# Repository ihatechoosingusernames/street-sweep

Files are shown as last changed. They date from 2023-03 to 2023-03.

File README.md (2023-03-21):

# street-sweep
A low cost version of the Ferris Sweep ergonomic keyboard.

Based on a [CH552G](https://raw.githubusercontent.com/WeActStudio/WeActStudio.CH552CoreBoard/master/Datasheet/CH552DS1_en.PDF) chip, this PCB can be completely constructed with all components apart from MX switches by JLCPCB for a total of €27.28 (5x PCBs), making for a per-keyboard cost of €10.91.

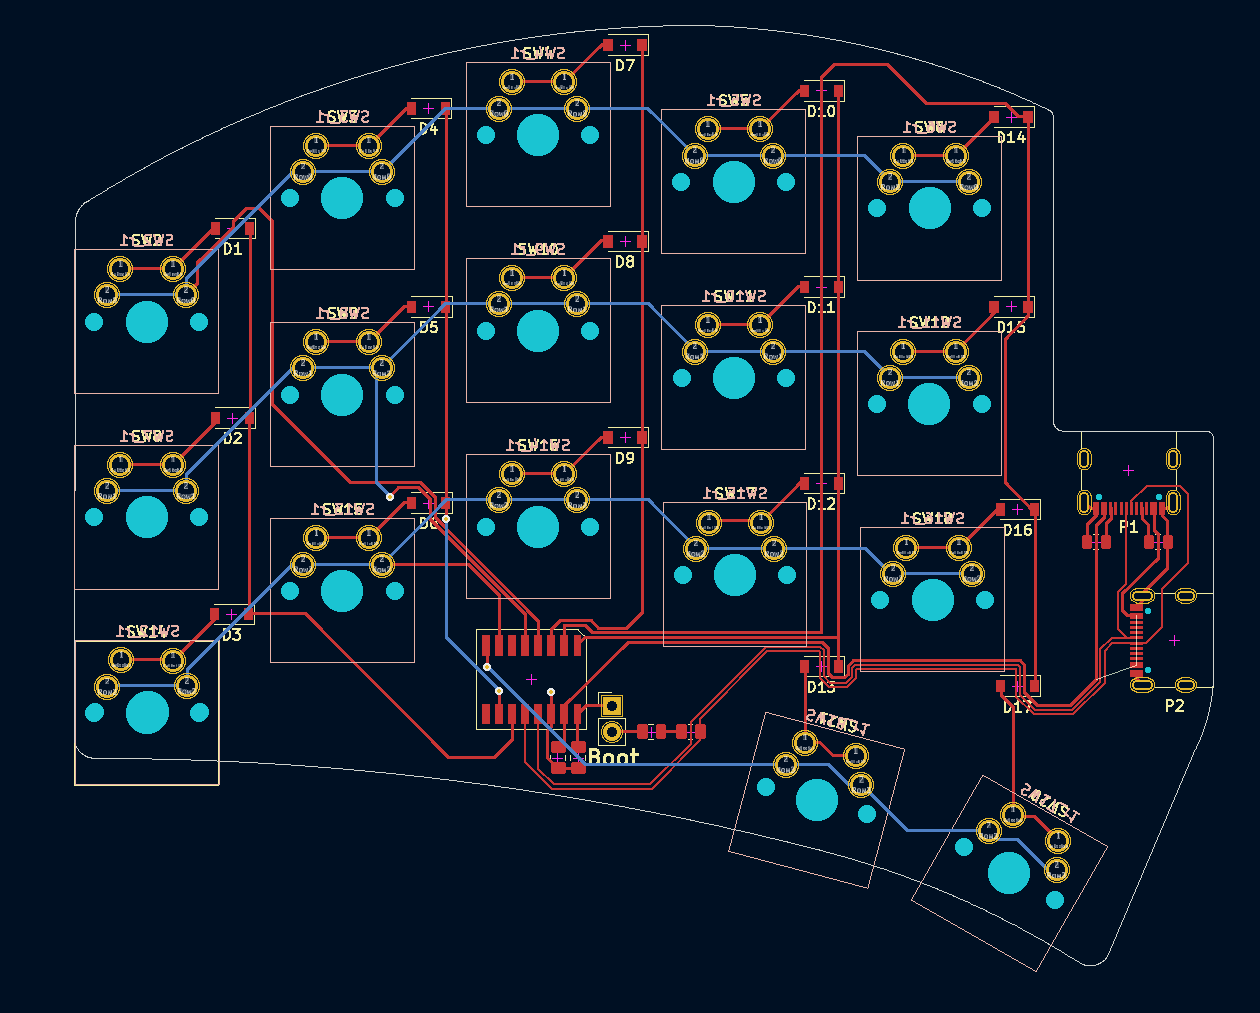
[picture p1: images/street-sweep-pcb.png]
PCB Layout


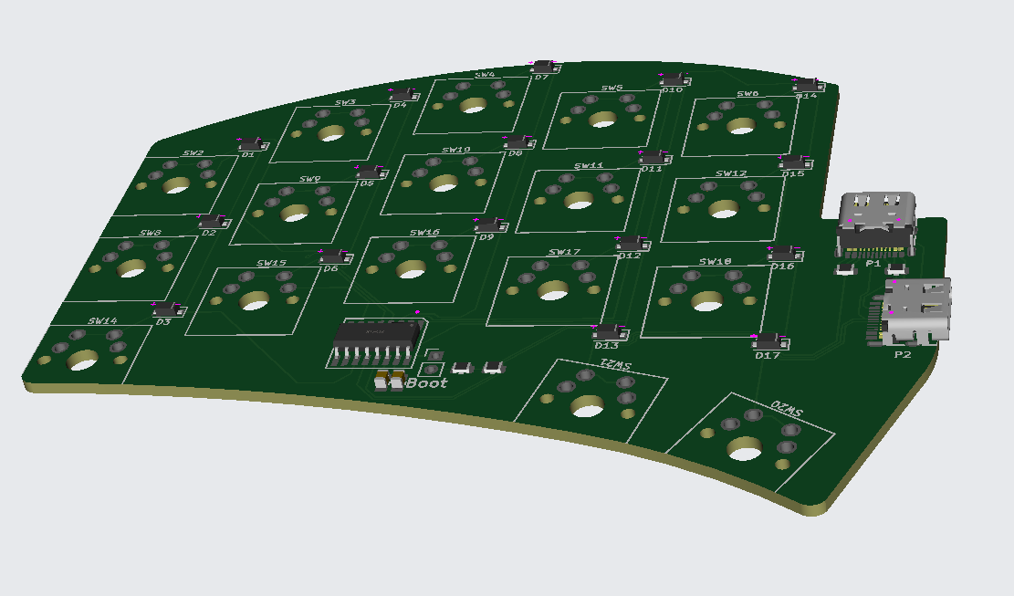
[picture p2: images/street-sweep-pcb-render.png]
PCB 3D Render


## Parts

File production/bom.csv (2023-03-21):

Designator | Footprint | Quantity | Value | LCSC Part #
C1 | 0805 | 1 | 0.1uF
C2 | 0805 | 1 | 0.1uF
D1, D10, D11, D12, D13, D14, D15, D16, D17, D2, D3, D4, D5, D6, D7, D8, D9 | D_SOD-123 | 17 | 1N4148
JP1 | PinHeader_1x02_P2.54mm_Vertical | 1 | Boot
P1, P2 | USB_C_Receptacle_G-Switch_GT-USB-7010ASV | 2 | GT-USB-7010ASV
R1 | 0805 | 1 | 5.1k
R2 | 0805 | 1 | 5.1k
R3 | 0805 | 1 | 5.1k
R4 | 0805 | 1 | 5.1k
SW10, SW10_r1, SW11, SW11_r1, SW12, SW12_r1, SW13_r1, SW14, SW14_r1, SW15, SW15_r1, SW16, SW16_r1, SW17, SW17_r1, SW18, SW18_r1, SW2, SW20, SW21, SW2_r1, SW3, SW3_r1, SW4, SW4_r1, SW5, SW5_r1, SW6, SW6_r1, SW7_r1, SW8, SW8_r1, SW9, SW9_r1 | SW_Cherry_MX_1.00u_PCB | 34 | SW_Push
U1 | CH552G | 1 | CH552G

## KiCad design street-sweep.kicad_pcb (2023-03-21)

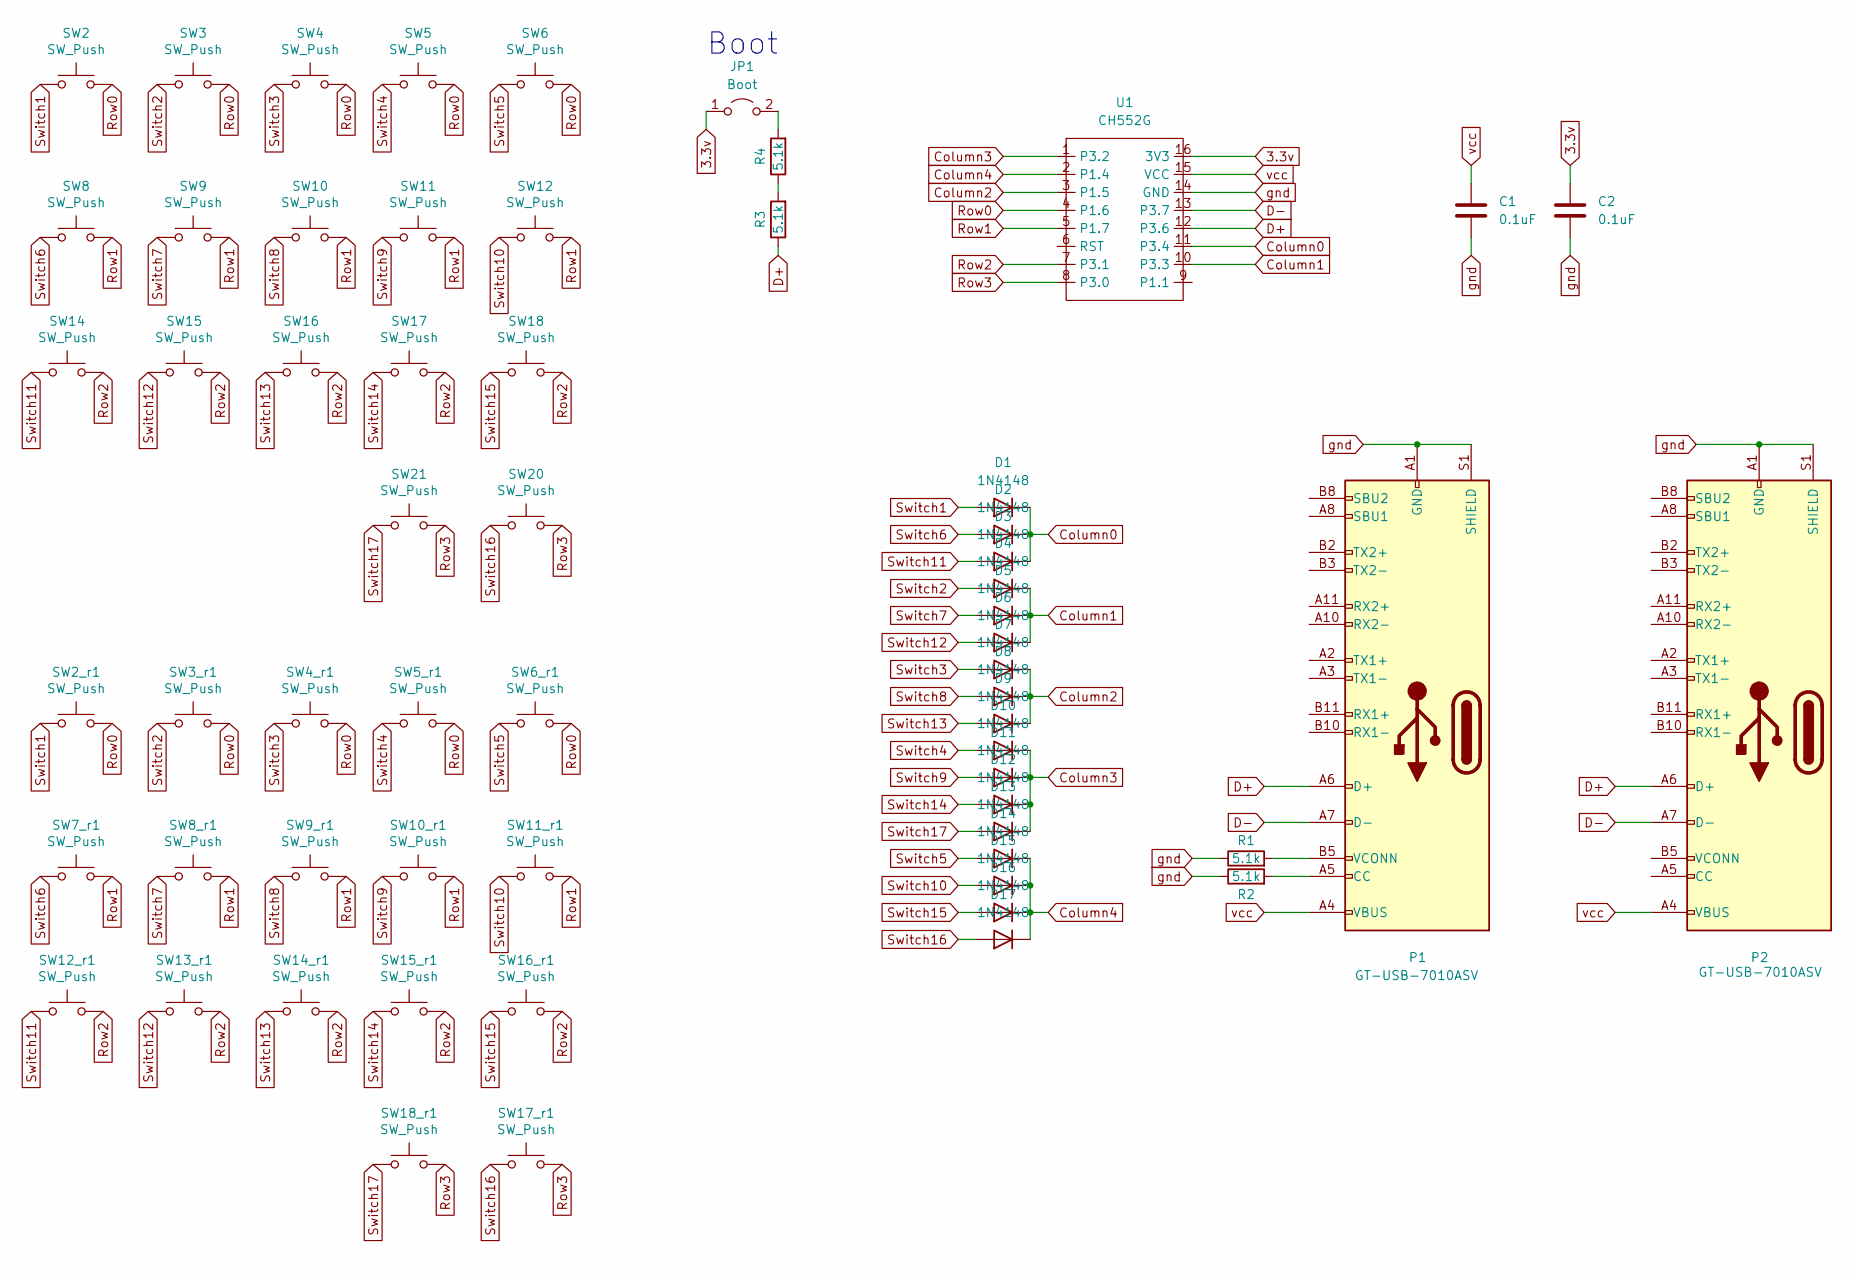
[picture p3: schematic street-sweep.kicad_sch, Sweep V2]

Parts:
C1, C2: 0.1uF; C_0805_2012Metric_Pad1.18x1.45mm_HandSolder
D1, D2, D3, D4, D5, D6, D7, D8, D9, D10, D11, D12, D13, D14, D15, D16, D17: 1N4148; D_SOD-123
JP1: Boot; PinHeader_1x02_P2.54mm_Vertical
P1, P2: GT-USB-7010ASV; USB_C_Receptacle_G-Switch_GT-USB-7010ASV
R1, R2, R3, R4: 5.1k; R_0805_2012Metric
SW2, SW2_r1, SW3, SW3_r1, SW4, SW4_r1, SW5, SW5_r1, SW6, SW6_r1, SW7_r1, SW8, SW8_r1, SW9, SW9_r1, SW10, SW10_r1, SW11, SW11_r1, SW12, SW12_r1, SW13_r1, SW14, SW14_r1, SW15, SW15_r1, SW16, SW16_r1, SW17, SW17_r1, SW18, SW18_r1, SW20, SW21: SW_Push; SW_Cherry_MX_1.00u_PCB
U1: CH552G

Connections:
3.3v: C2.1, JP1.1 (A), U1.16 (3V3)
Column0: D1.1 (K), D2.1 (K), D3.1 (K), U1.11 (P3.4)
Column1: D4.1 (K), D5.1 (K), D6.1 (K), U1.10 (P3.3)
Column2: D7.1 (K), D8.1 (K), D9.1 (K), U1.3 (P1.5)
Column3: D10.1 (K), D11.1 (K), D12.1 (K), D13.1 (K), U1.1 (P3.2)
Column4: D14.1 (K), D15.1 (K), D16.1 (K), D17.1 (K), U1.2 (P1.4)
D+: P1.A6 (D+), P2.A6 (D+), R3.1, U1.12 (P3.6)
D-: P1.A7 (D-), P2.A7 (D-), U1.13 (P3.7)
unnamed: JP1.2 (B), R4.2
unnamed: P1.A5 (CC), R2.2
unnamed: P1.B5 (VCONN), R1.2
unnamed: R3.2, R4.1
Row0: SW2.2, SW2_r1.2, SW3.2, SW3_r1.2, SW4.2, SW4_r1.2, SW5.2, SW5_r1.2, SW6.2, SW6_r1.2, U1.4 (P1.6)
Row1: SW7_r1.2, SW8.2, SW8_r1.2, SW9.2, SW9_r1.2, SW10.2, SW10_r1.2, SW11.2, SW11_r1.2, SW12.2, U1.5 (P1.7)
Row2: SW12_r1.2, SW13_r1.2, SW14.2, SW14_r1.2, SW15.2, SW15_r1.2, SW16.2, SW16_r1.2, SW17.2, SW18.2, U1.7 (P3.1)
Row3: SW17_r1.2, SW18_r1.2, SW20.2, SW21.2, U1.8 (P3.0)
Switch1: D1.2 (A), SW2.1, SW2_r1.1
Switch2: D4.2 (A), SW3.1, SW3_r1.1
Switch3: D7.2 (A), SW4.1, SW4_r1.1
Switch4: D10.2 (A), SW5.1, SW5_r1.1
Switch5: D14.2 (A), SW6.1, SW6_r1.1
Switch6: D2.2 (A), SW7_r1.1, SW8.1
Switch7: D5.2 (A), SW8_r1.1, SW9.1
Switch8: D8.2 (A), SW9_r1.1, SW10.1
Switch9: D11.2 (A), SW10_r1.1, SW11.1
Switch10: D15.2 (A), SW11_r1.1, SW12.1
Switch11: D3.2 (A), SW12_r1.1, SW14.1
Switch12: D6.2 (A), SW13_r1.1, SW15.1
Switch13: D9.2 (A), SW14_r1.1, SW16.1
Switch14: D12.2 (A), SW15_r1.1, SW17.1
Switch15: D16.2 (A), SW16_r1.1, SW18.1
Switch16: D17.2 (A), SW17_r1.1, SW20.1
Switch17: D13.2 (A), SW18_r1.1, SW21.1
gnd: C1.2, C2.2, P1.A1 (GND), P1.A12 (GND), P1.B1 (GND), P1.B12 (GND), P1.S1 (SHIELD), P2.A1 (GND), P2.A12 (GND), P2.B1 (GND), P2.B12 (GND), P2.S1 (SHIELD), R1.1, R2.1, U1.14 (GND)
vcc: C1.1, P1.A4 (VBUS), P1.A9 (VBUS), P1.B4 (VBUS), P1.B9 (VBUS), P2.A4 (VBUS), P2.A9 (VBUS), P2.B4 (VBUS), P2.B9 (VBUS), U1.15 (VCC)

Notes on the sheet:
Boot

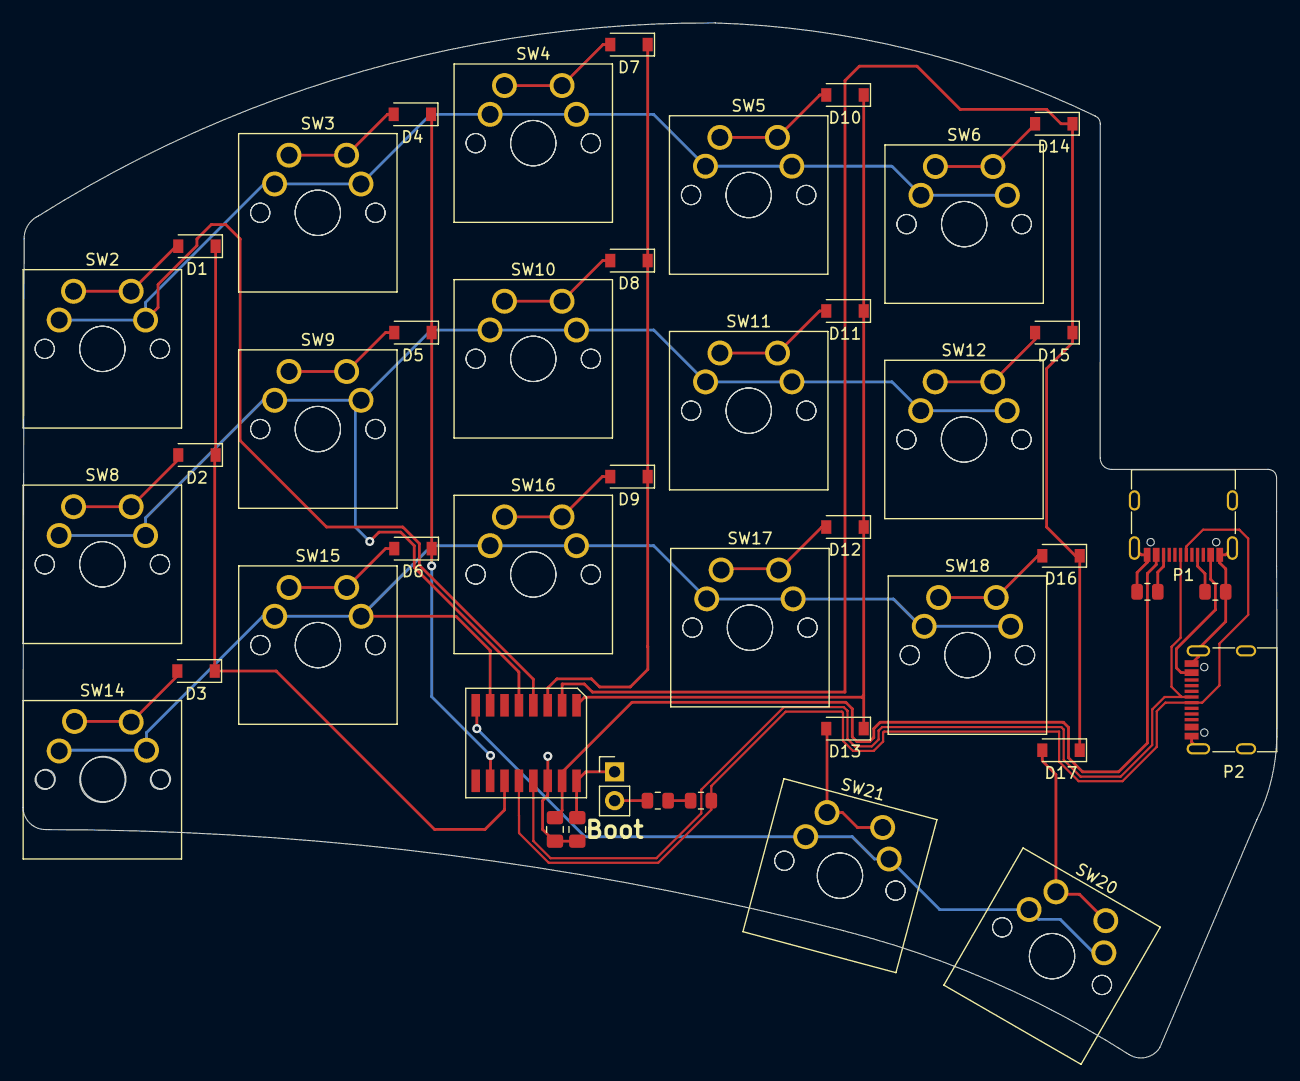
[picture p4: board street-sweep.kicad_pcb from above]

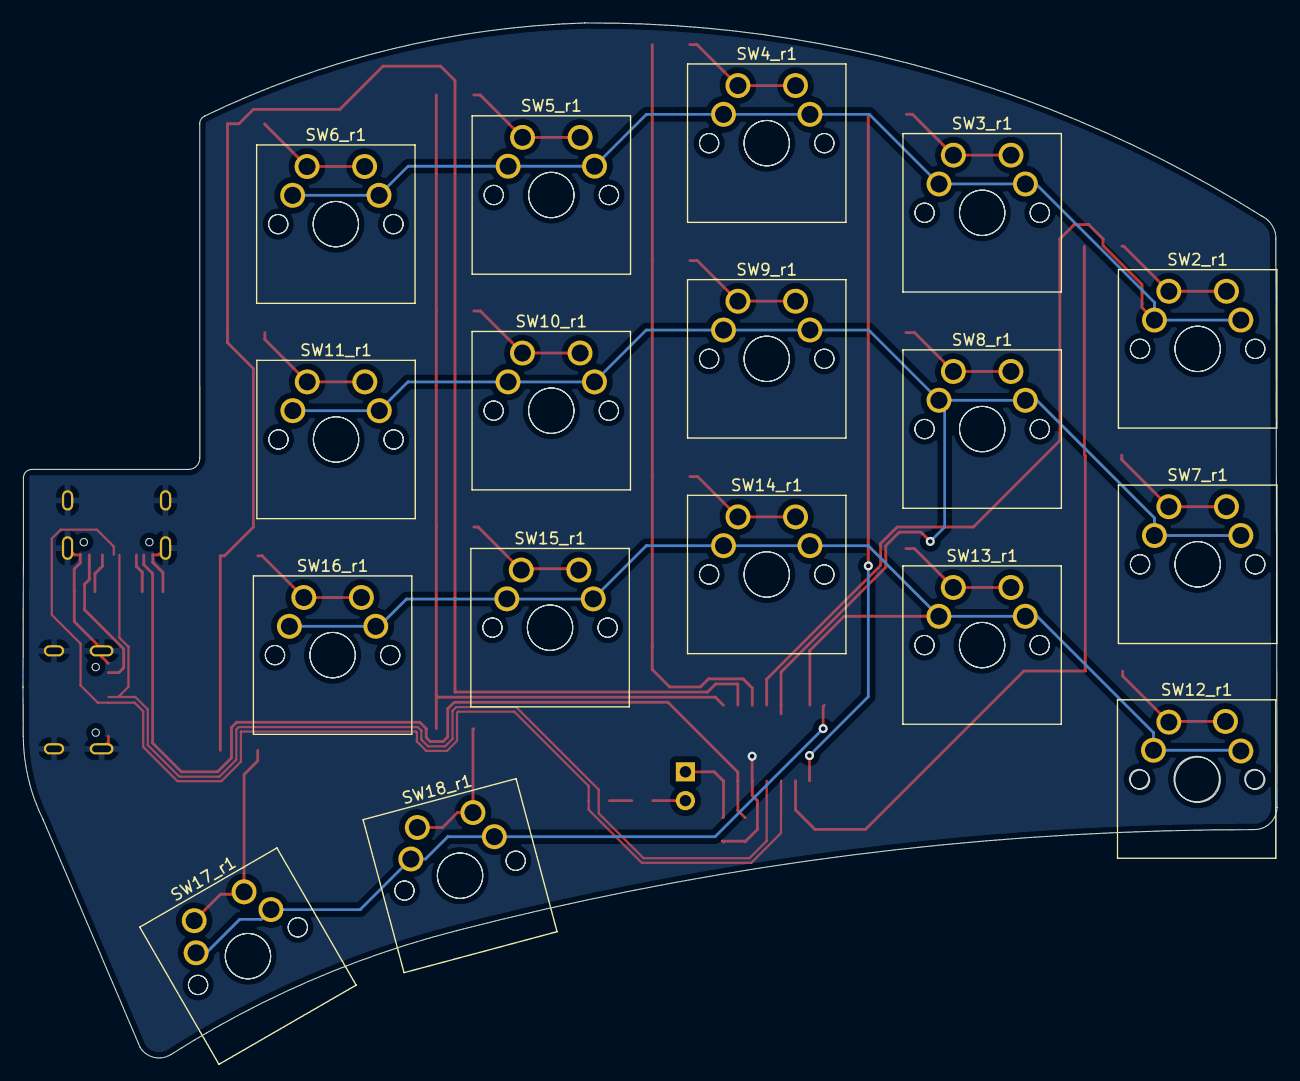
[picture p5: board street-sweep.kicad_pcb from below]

Board: 2 copper layers, 110.6 x 91.3 mm, 61 parts (17 on the bottom side), 35 nets.

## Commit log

2023-03-21 Laid out CH552 Board version with two USB-C ports and fixes for flashing.
    [bom.csv, designators.csv, positions.csv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]
2023-03-21 Added render image, updated readme.
    [street-sweep.kicad_pcb]
